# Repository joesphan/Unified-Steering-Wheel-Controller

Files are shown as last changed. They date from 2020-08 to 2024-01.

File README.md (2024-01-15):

# Unified Sim Controller

# Due to safety concerns with the mige 30 servo, this project was abandoned. The story goes is a bug occured, the wheel flung off, and drove into my monitor. In the future I might revisit with a appropriate sized servo motor.

##### Done:

- hardware done
- hardware differential centering upon power loss implemented
- firmware mostly complete
- overspeed safety implemented
- endstop damping implemented
- flowchart
- Wireless perhipherals: wheel buttons, pedals, shifter

##### Todo:

- documentation of code
- wheel damping adjustment
- figure out how to drop the 220v transformer
- add calibrate wheel button, gain adjustment potentiomter, etc.
- PCB boards
- standardized enclosure

## Theory of Operation

Controller for FFB wheel and peripherals

-Atmega 32u4

-[FFB Library](https://github.com/joesphan/ArduinoJoystickWithFFBLibrary) (thanks to the original author)

-Generic Servo Drive

-cutomizable and expandable controller

-wireless perhipheral add-ons (check docs for more detail)

## Servo Drive

The unified controller board's output is a standard CNC differential +/-10V + EN signal to control the motor.

## Encoder

Run with interrupts from servo drive. Two phase bog standard signal.

## Code Documentation

under \Documentation

## DIY kits and fully assembled

Want to help me pay for my tuition? DIY kits and fully assembled controller kits will be available soon. It will include a case and everything you need to assemble/PnP yourself. Target cost is around $50.

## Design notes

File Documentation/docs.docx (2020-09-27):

https://github.com/joesphan/FFB-Steering-Wheel

Design Goal:

Inspired by the Marlin firmware for 3d printers, the goal of this project is to create something that everyone can use, using a familiar Arduino interface, and create compatibility across a range of parts

Main features:

- Open source
  - Unlike MMOS, the source code can be viewed by everyone
  - Changes and improvements can be made/suggested by opening an issue on github
- Universal CNC servo drive control interface
  - The sim wheel controller is capable of driving servo drives with a +/- 10V signal
- Wireless peripherals
  - Pedals, yoke, shifters can all easily be added using one of the four auxiliary DB9 ports, or through the wireless ESP8266 UDP interface
  - The ESP8266 UDP interface has a latency of 20ms
- Easy configuration
  - All the parameters are set via the #defines tab

Basic Connection:

The minimal connections require a set of feedback and control signals to the servo drive.

The connections and code naming conventions are as follows:

Name | Pin | Description
DI1 | 10 | -10V to EN motor, in reference to COM+
COM+ | 18 | See above
A+ | 1 | Encoder phase A, ref to DGND
B+ | 3 | Encoder phase B, ref to DGND
DGND | 9 | Digital ground
AS+ | 20 | Differential + of control, +/-10V
AS- | 19 | Differential - of control, +/-10V
AGND | 22 | Differential ground reference

Firmware Setup:

Everything is contained under the defines tab

1. //Safetys
2. #define MAX_RPM 1
3. #define MOT_EN_PIN 7
5. //encoder parameters
6. #define MAX_STEPS 15000 //maximum number of steps one way
7. #define MAX_FULL_STEPS (MAX_STEPS * 2) //max number of steps total
9. //encoder HW
10. #define ENCODER1_PIN 3 //must support external interrupt
11. #define ENCODER2_PIN 2 // "" "" "" ""
13. //encoder RPM detect
14. #define ENCODER_1_REV 10000
15. #define RPM_DIVIDEND (60000000 / ENCODER_1_REV)
17. //motor control HW
18. #define ADC_PIN 5
20. //endstop damping settings: https://www.desmos.com/calculator/rhyetd6p3d
21. #define ENDSTOP_FACTOR 2.5 //dampening factor when turned past full lock
22. #define MAX_OVERTRAVEL 100 //how much overtravel steps is allowed before full force is applied
23. #define BIT_DEPTH 2048
25. //endstop rebound settings:
26. #define REBOUND_FORCE 50 //rebound force proportion to speed
28. //endstop spring length
29. #define OVERTRAVEL_SLOPE (BIT_DEPTH / MAX_OVERTRAVEL) //internal calcs

formatter (http://www.planetb.ca/syntax-highlight-word)

Some of the settings that require more thought are the rebound and dampening settings.

For endstop dampening, one can refer to this desmos graph (https://www.desmos.com/calculator/v05nhapfn8) when the wheel is moving towards more overtravel.

Endstop rebound dampening of is just a linear relationship between speed towards wheel center and REBOUND_FORCE

A library is used for communication with the PC. Be sure to use my fork (https://github.com/joesphan/ArduinoJoystickWithFFBLibrary), as it offers 12 bit (adjustable) FFB resolution, rather than fixed 8 bit.

Flow Diagrams:

- PID Loop:

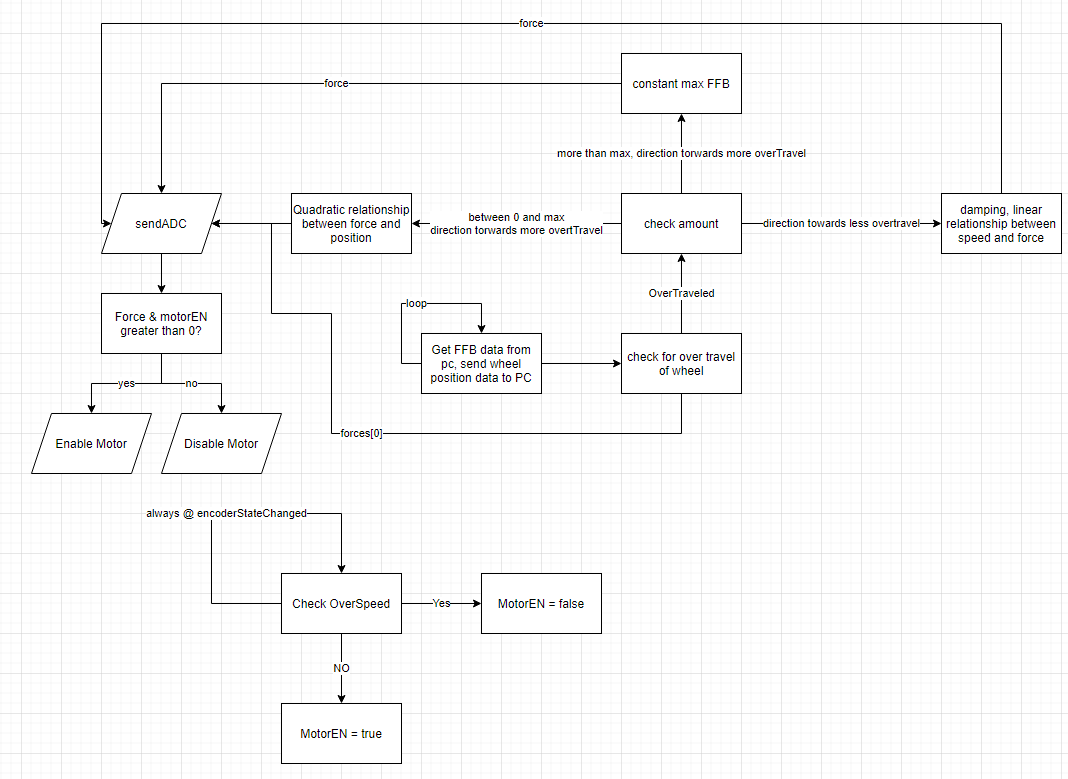
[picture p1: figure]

- Hardware Diagram:

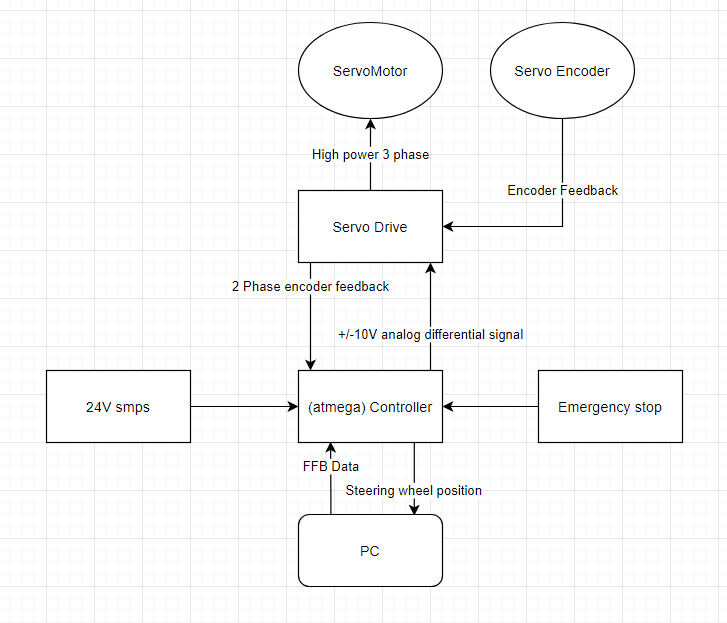
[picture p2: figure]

- Controller circuit flow diagram:

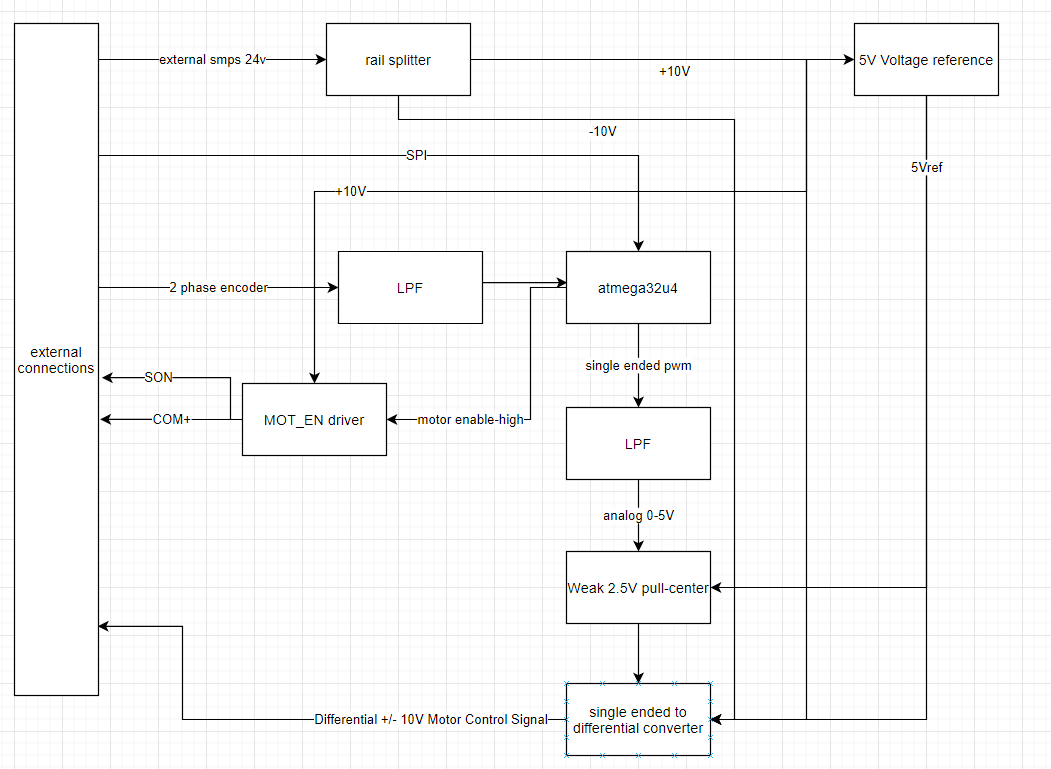
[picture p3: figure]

Wired Peripherals:

- All the remaining pins on the Arduino micro have been broken out to the DB9
- The pinouts can be found under fullschematic.dch/.pdf

Wireless Peripherals:

This method requires building a ESP8266 DB9 wireless adapter and plugging into DSUB-1. The ESP Wi-Fi receiver will communicate to the ATMega32u4 via UART. A custom packet is used to communicate information between peripheral and controller, through Wi-Fi UDP. The UDP packet is as follows:

Function | HEADER | Byte 1 | | | | | | | | Byte 2 | | | | | | | | Byte 3 | Byte 4 | Byte 5 | Byte 6 | Byte n
| | Bit7 | Bit6 | Bit5 | Bit4 | Bit3 | Bit2 | Bit1 | Bit0 | Bit7 | Bit6 | Bit5 | Bit4 | Bit3 | Bit2 | Bit1 | Bit0
Button input 1 | ‘A’ | | | | | | Horn (Button18) | Left shift paddle (Button0) | Right shift paddle (Button 1)
Axis input 1 | ‘B’ | Throttle, high 8 bits of the 16 | | | | | | | | Throttle, low 8 bits of the 16 | | | | | | | | Brake, high 8 bits of the 16 | Brake, low 8 bits of the 16 | Clutch, high 8 bits of the 16 | Clutch, low 8 bits of the 16
Button input 2 | ‘C’ | Reverse gear (Button2) | Gear 1 (Button3) | Gear 2 (Button4) | Gear 3 (Button5) | Gear 4 (Button6) | Gear 5 (Button7) | Gear 6 (Button8) | Gear 7 (Button9) | Gear 8 (Button10) | Gear 9 (Button11) | Gear 10 (Button12) | Shifter console button 1 (Button13) | Shifter console button 2 (Button14) | Shifter console button 3 (Button15) | Shifter console button 4 (Button16) | Shifter console button 5 (Button17)
Axis input 2 | ‘D’ | Handbrake, high 8 bits of the 16 | | | | | | | | Handbrake, low 8 bits of the 16

Coding conventions:

0x01 is recognized as HIGH for buttons, therefore it is active HIGH.

0x00 is recognized as LOW for buttons

The peripheral will automatically connect to the host Wi-Fi access point and send the packet to the host ESP8266 via UDP.

AP: SimInput

Key: 12345678

IP to send to: 192.168.4.1

Port to send to: 4210

Official Peripheral Documentation

Please open an issue and provide documentation, and Github page link to get the peripheral officially listed.

Shifter Paddles

Github: https://github.com/joesphan/Wireless-shifter-Paddles

Header used: ‘A’

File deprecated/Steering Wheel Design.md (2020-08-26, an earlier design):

# Custom Steering Wheel

## Theory of Operation

-needs to be easy to replicate on the HFT corded drill

-Atmega 32u4

-[FFB Library](https://github.com/YukMingLaw/ArduinoJoystickWithFFBLibrary) (thanks!)

-drill motor for "direct drive"

-minimize the use of 3d printed high stress components

-3d print a encoder wheel and use IR sensors to implement a rotary encoder built into the motor

-old 2 bay NAS chassis for housing

## Schematics

[Complete Schematic (pdf)](https://github.com/joesphan/Fullmotion-Racing-Sim/blob/master/Steering%20Wheel/Controller/Schematics%20and%20simulation/FullSchematic.pdf)

[Complete Schematic (diptrace)](https://github.com/joesphan/Fullmotion-Racing-Sim/blob/master/Steering%20Wheel/Controller/Schematics%20and%20simulation/FullSchematic.dch)

Note: 12V net port is not actually 12V

## MadCatz xbox wheel

| Color/Stripe | Function |
| :---: | :---: |
| Blue/Black | GND |
| Green/White | Y |
| Green | X |
| Orange/White | B |
| Yellow/Black | A |
| Blue/White | RSB |
| Red/White | LSB |
| Blue | RB (Flappy paddle right) |
| [Brown](https://youtu.be/lzqCQxi3ENE) | LB (Flappy paddle left)  |
| Yellow/Orange | Back |
| Black | Start |
| Gray | Xbox Button |
| Yellow | Up |
| Gray/White | Down |
| Brown/White | Left |
| Orange | Rumble Motor Left |
| Purple | Rumble Motor Right |
| Red | Vcc |
| White | 5V |
| Orange/Black | P1 LED (active low, use resistor) |
| Red/Black | P2 LED (active low, use resistor) |
| Brown/Black | P3 LED (active low, use resistor) |
| Pink/Black | P4 LED (active low, use resistor) |

The steering wheel will carry an onboard SPI IO expander (mcp23s17), interfacing with all the buttons.

A spring cable will carry the SPI signals between the 32u4 and the wheel.

## Microcontroller Flowchart

diagram

Inside the ATmega32u4, the code will go something like this:

diagram

## Rotary Encoder

To eliminate the need of any mechanical connection between the drill and parts, the cooling fan inside the motor will be replaced with a rotary encoder wheel.

## H bridge Driver

This is a basic H bridge driver, supports PWM. Only thing is that there is absolutely no circuit protection, so should both analog pwm inputs be active, the HEXFETS will be no more.

The extra transistors tacked on are to create a 12V gate drive.

I simulated the circuit in [circuitmod](https://sourceforge.net/projects/circuitmod/). Although I had access to MultiSim through my uni, the mentioned software is more accessible to most people and is fine.

HBridgeSimulation

The non-full voltage swing across the 10 ohm is caused by the limitation of the simulator's mosfet model. Putting another one in parallel solves this issue, by using a more appropriate MOSFET in the final design will be a better solution

## Power supply

The drill is a 120V drill. Running it on 12V DC provides good Locking torque, yet lacks power to come out of a locked stall.

A voltage doubler circuit would be utilized to boost the voltage to a decent amount.

### Transformer calculations

TrafoInductanceTest

The circuit consisted of the transformer (secondary open) and a 100 ohm resistor in series. The smaller waveform is the measurement across the resistor while a signal was applied.

Calculations

formula

formula

formula

formula

formula

### Voltage doubler and filter simulation

PowerSupplySim

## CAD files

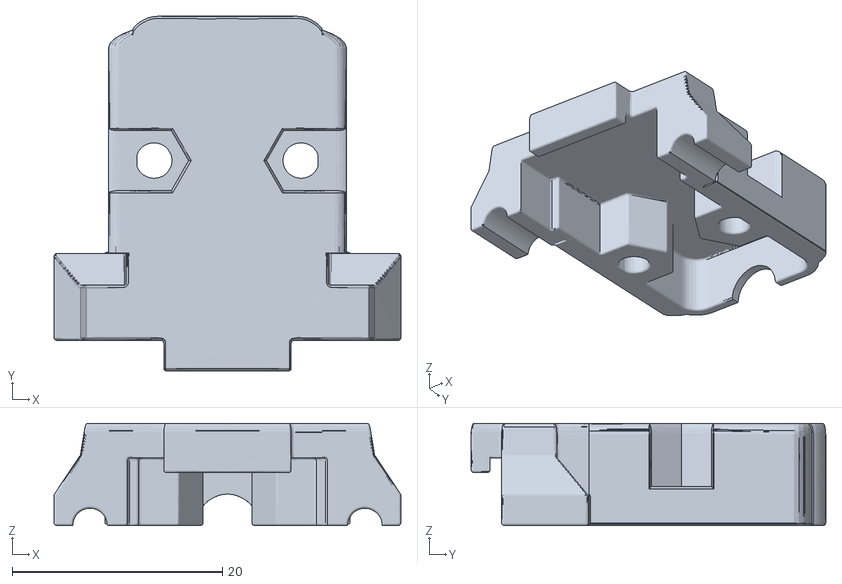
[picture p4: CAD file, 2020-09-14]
Chassis/DSub/DB9-industrial.stl
33.0 x 33.7 x 9.73

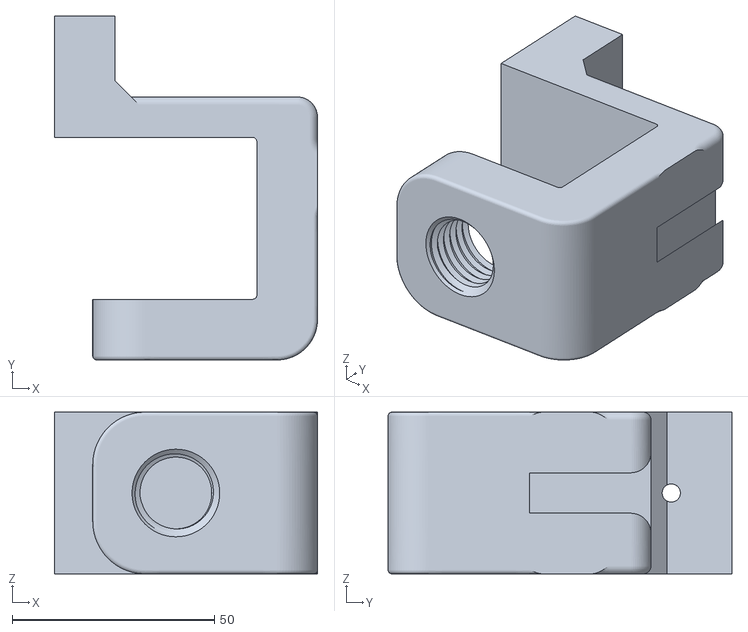
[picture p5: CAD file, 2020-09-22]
Wheel/clamp mount/clamp.stl
65.0 x 85.0 x 40.0

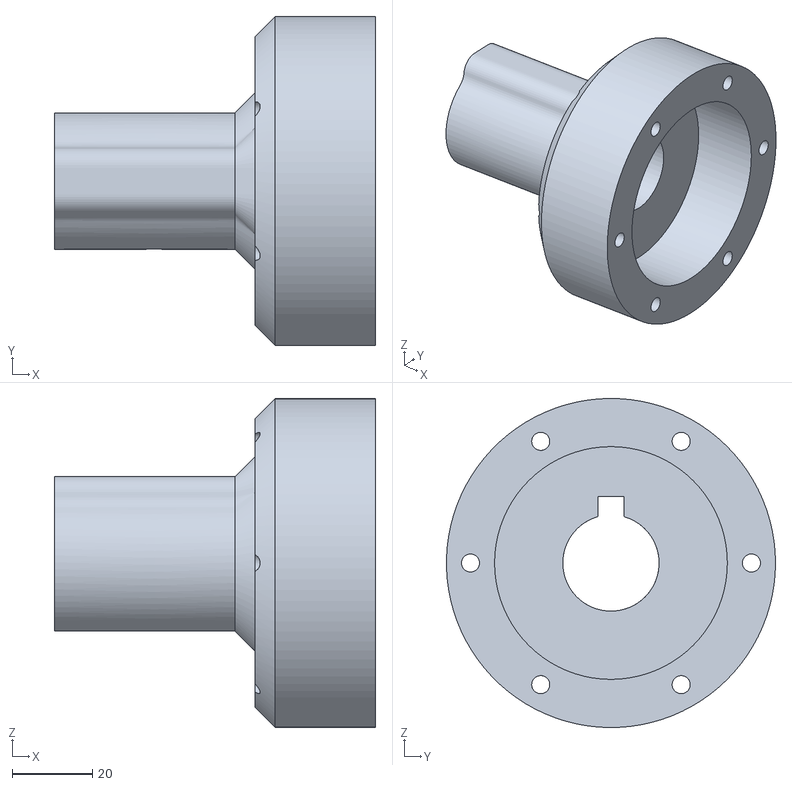
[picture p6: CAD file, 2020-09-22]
Wheel/6 bolt steering wheel adapter/adapter.stl
80.0 x 82.0 x 82.0

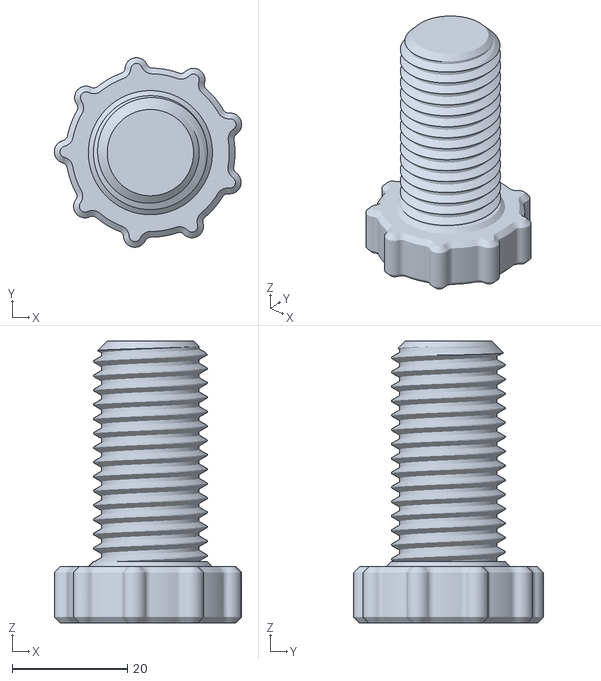
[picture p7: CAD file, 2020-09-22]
Wheel/clamp mount/screw.stl
32.6 x 33.0 x 49.0

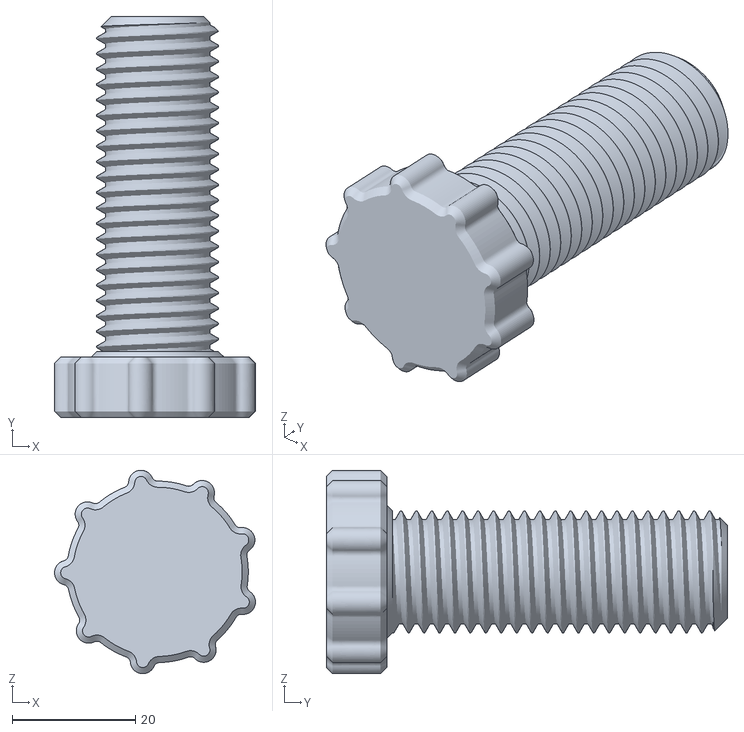
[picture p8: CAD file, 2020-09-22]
Wheel/clamp mount/screw_long.stl
32.6 x 65.0 x 33.0

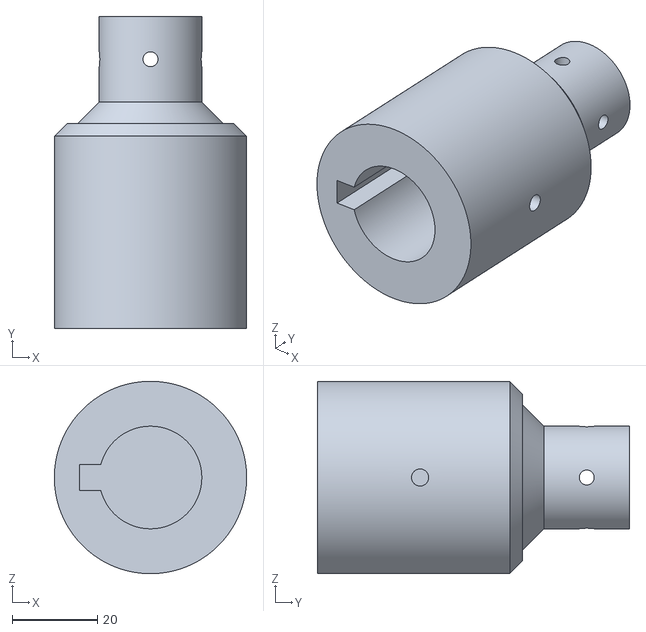
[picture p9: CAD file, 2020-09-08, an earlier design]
deprecated/3d models/Xbox Madcatz Wheel/shaft adapter.stl
45.0 x 73.0 x 45.0

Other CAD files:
Chassis/ESP Receiver/OldVersions/dongle shell.0001.ipt
Chassis/ESP Receiver/dongle shell.ipt
Wheel/6 bolt steering wheel adapter/OldVersions/adapter.0003.ipt
Wheel/6 bolt steering wheel adapter/adapter.ipt
deprecated/3d models/Assembly1.iam
deprecated/3d models/IRSensorMount.ipt
deprecated/3d models/IRSensorMountOtherSide.ipt
deprecated/3d models/OldVersions/Assembly1.0007.iam
deprecated/3d models/OldVersions/Bearing.0002.ipt
deprecated/3d models/OldVersions/IRSensorMount.0002.ipt
deprecated/3d models/OldVersions/IRSensorMount.0007.ipt
deprecated/3d models/OldVersions/IRSensorMountOtherSide.0007.ipt
deprecated/3d models/OldVersions/back plate.0010.ipt
deprecated/3d models/OldVersions/back plate.0015.ipt
deprecated/3d models/OldVersions/front plate.0009.ipt
deprecated/3d models/OldVersions/motor mount.0002.ipt
deprecated/3d models/OldVersions/rotary encoder.0003.ipt
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

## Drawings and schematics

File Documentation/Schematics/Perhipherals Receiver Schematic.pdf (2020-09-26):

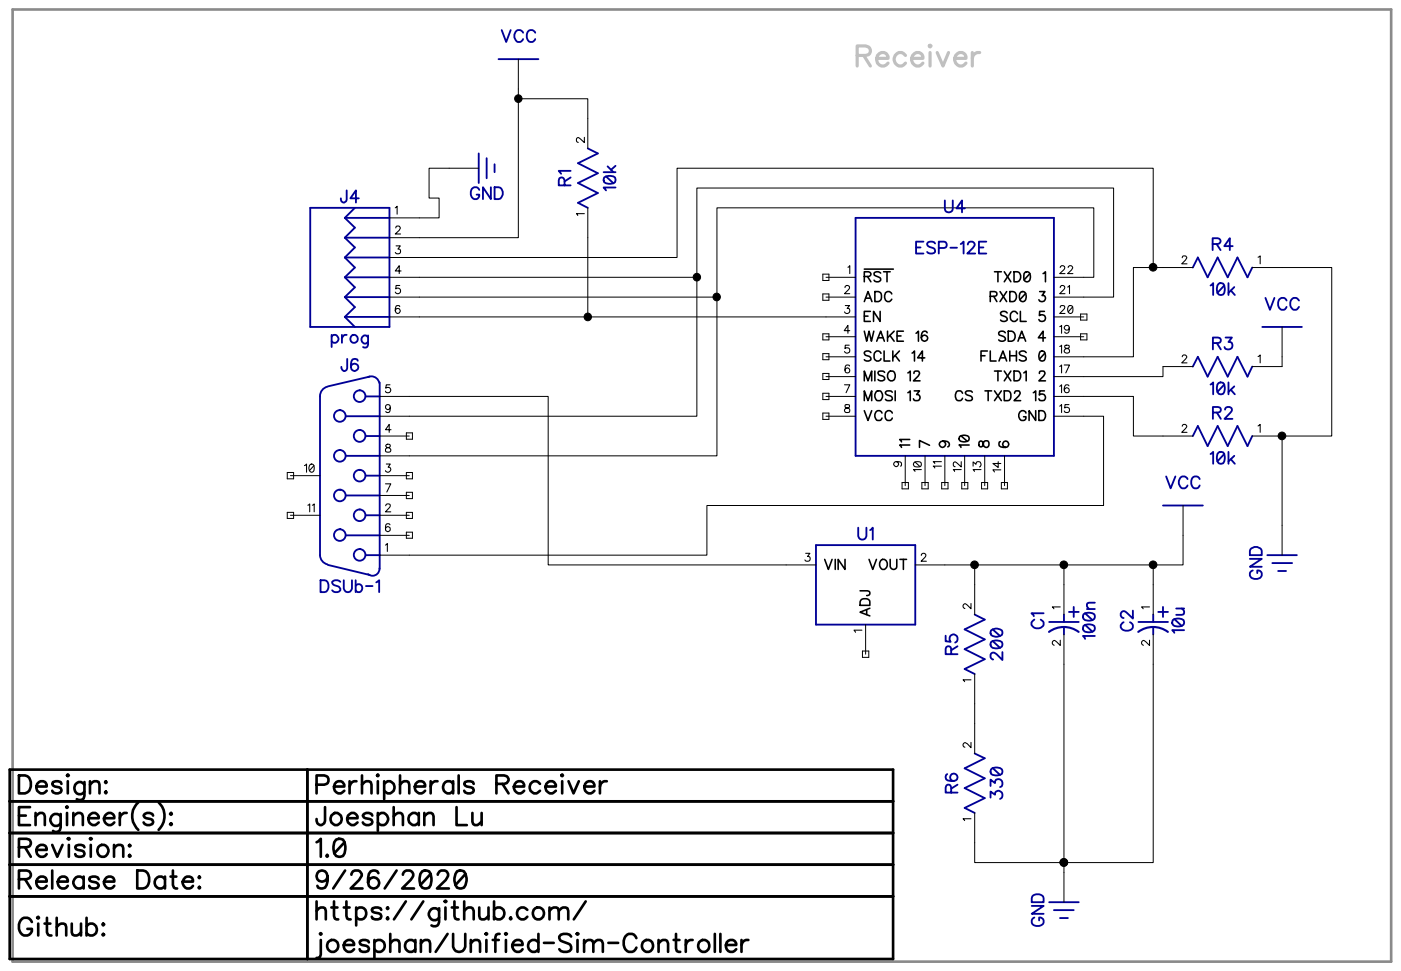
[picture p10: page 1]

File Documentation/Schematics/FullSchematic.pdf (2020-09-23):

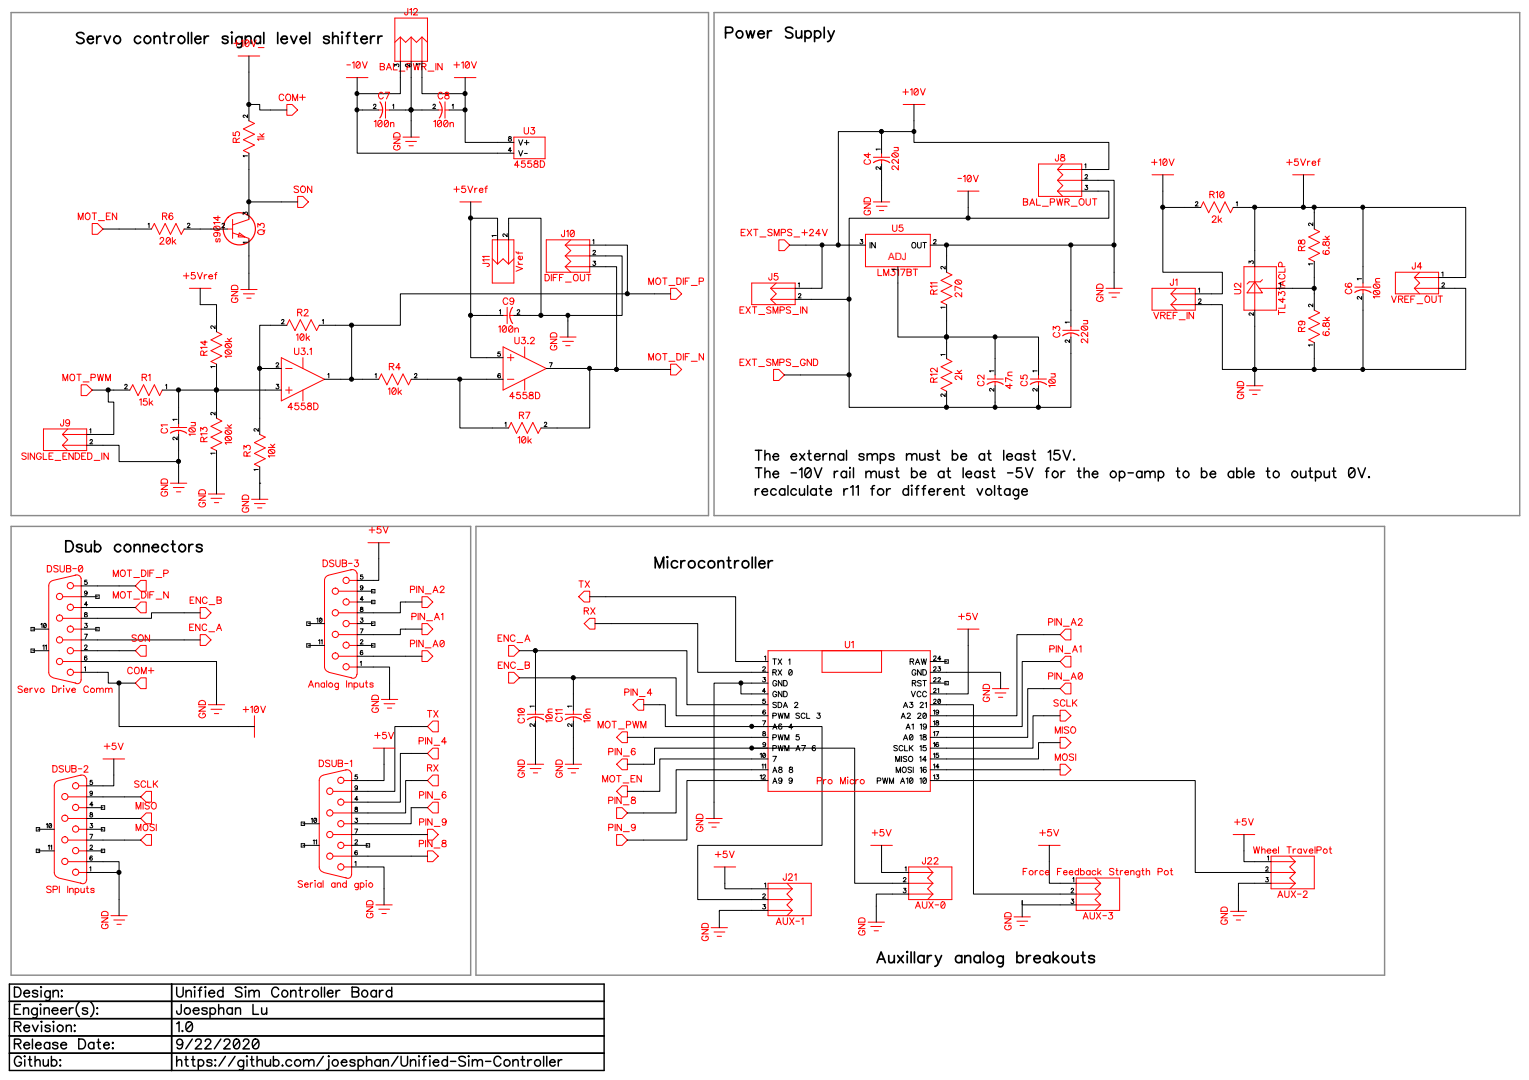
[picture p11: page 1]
ADJ

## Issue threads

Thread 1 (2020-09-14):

I have a project about racing simulation direct drive steering wheel diy

HUANGJIN169, 2020-09-14:
Hello there
How do you use these firmware
I have a project about racing simulation direct drive steering wheel diy
https://hackaday.io/project/168801-diy-mmos-ffb-stm32-and-servo-drive-servo-motor
I need a perfect firmware to control
can you do it?
Thank you!

joesphan, 2020-09-14:
Hello! I saw your project and was part of my inspiration. I will do a push later today for the schematic and firmware. It's pretty self explanatory.
The goal of this project is fully open source, unlike MMOS. The MCU is atmega32u4, I'm sure it can be implemented with the STM32 through stm32duino, no library dependencies are being used. The controls are a PWM output, with 0 being max force servo left, 4096 being max force servo right.
Hopefully I can get it all documented before uni starts again.

HUANGJIN169, 2020-09-15:
Thank you for your reply
If you have time to complete my project control firmware
You send me the first time
I test if it can be used
Thank you
You have worked hard

Joesphan Lu <notifications@github.com> 于2020年9月15日周二 上午12:20写道：

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

HUANGJIN169, 2020-09-15:
I come from Google Translate, it may not be very standard
Hope to understand

DIY Racing Simul <huangjin169@gmail.com> 于2020年9月15日周二 下午5:09写道：

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

joesphan, 2020-09-15:
Could you put what you wanted to say in Chinese underneath? I can read Chinese.

HUANGJIN169, 2020-09-16:
我意思是，如果你把固件设计完成了
就把固件和运行软件发给我，我来测试固件是不是可以控制伺服驱动和电机
我这个直驱模拟方向盘是由伺服驱动和伺服电机进行diy的
所以我需要一个属于自己的固件和控制界面
我也希望你能做出来的固件 这样我们以后就有自己的固件了
谢谢你的回复！

Joesphan Lu <notifications@github.com> 于2020年9月15日周二 下午9:56写道：

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

HUANGJIN169, 2020-09-16:
https://github.com/hoantv
还有，这里有一个也开放项目，他这个代码是可以完全和MMOS一样的
他这个固件也可以完全控制我的diy项目的
不过，他设计的界面不是很完美

DIY Racing Simul <huangjin169@gmail.com> 于2020年9月16日周三 下午12:44写道：

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

joesphan, 2020-09-16:
Sounds good, I will put a release once I finish testing the wheel. Pcb are in shipping right now. Can you tell me the drawbacks of hoanTV's firmware?

HUANGJIN169, 2020-09-17:
它的缺点，界面不是很完美
固件好在优化中
使用hoanTV固件的时候和MMOS一样的
就是界面不一样而且
我想要的界面就是像Simucube一样

Joesphan Lu <notifications@github.com> 于2020年9月16日周三 下午9:47写道：

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

HUANGJIN169, 2020-09-17:
https://github.com/SimuCUBE/SimuCUBE-OpenSource-Firmware
你可以使用这个开源固件做出来一个完美自己的固件吗？
我非常喜欢这个固件
不幸的是，我的伺服驱动器和我的伺服电机不能使用它
辛苦你了😧

DIY Racing Simul <huangjin169@gmail.com> 于2020年9月17日周四 下午12:47写道：

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

joesphan, 2020-09-17:
I'm not planning on putting in a computer interface, as adjusting the
settings in defines.ino is a one time thing. However, to make setup easier,
a c# program that sets the defines.ino parameters, compiles and flashes,
could be done. Generally speaking though, i have made it super easy to
change settings in firmware.

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

HUANGJIN169, 2020-09-18:
好的
能使用就可以
不管怎么样
这也是属于完美自己的固件了

Joesphan Lu <notifications@github.com> 于2020年9月17日周四 下午1:34写道：

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

HUANGJIN169, 2020-09-18:
RaceManager(V3.3) - 速魔.zip
<https://drive.google.com/file/d/1NUXp7nSRQALGHQiRQVS_OVzfGvQ5KJBX/view?usp=drive_web>
你可以解压这个固件
它来自中国一个模拟器的固件
它仿制Simucube固件的界面
这他们应该使用的是Simucbe开放软件进行制作的

DIY Racing Simul <huangjin169@gmail.com> 于2020年9月18日周五 下午12:24写道：

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

TadyTheFish, 2020-12-02:
Can't  compile for a STM32 :(

joesphan, 2020-12-02:
> Can't  compile for a STM32 :(

The USB libraries for stm32 are different. I couldn't find stm32 libraries that also did force feedback.

HUANGJIN169, 2020-12-11:
你好大哥
最近在忙工作吗？
我们之前谈话题，说要做模拟赛车方向盘控制软件的，你还记得吗？大哥
如果你有时间能帮助我写一个软件吗？
谢谢！

DIY Racing Simul <huangjin169@gmail.com> 于2020年9月18日周五 下午6:26写道：

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
>>> I'm not planning on putting in a computer interface, as adjusting the
>>> settings in defines.ino is a one time thing. However, to make setup
>>> easier,
>>> a c# program that sets the defines.ino parameters, compiles and flashes,
>>> could be done. Generally speaking though, i have made it super easy to
>>> change settings in firmware.
>>>
>>> On Thu, Sep 17, 2020, 3:47 AM huangjin <notifications@github.com> wrote:
>>>
>>> > 它的缺点，界面不是很完美
>>> > 固件好在优化中
>>> > 使用hoanTV固件的时候和MMOS一样的
>>> > 就是界面不一样而且
>>> > 我想要的界面就是像Simucube一样
>>> >
>>> > Joesphan Lu <notifications@github.com> 于2020年9月16日周三 下午9:47写道：
>>> >
>>> > > Sounds good, I will put a release once I finish testing the wheel.
>>> Pcb
>>> > are
>>> > > in shipping right now. Can you tell me the drawbacks of hoanTV's
>>> > firmware?
>>> > >
>>> > > —
>>> > > You are receiving this because you authored the thread.
>>> > > Reply to this email directly, view it on GitHub
>>> > > <
>>> >
>>> https://github.com/joesphan/FFB-Steering-Wheel/issues/1#issuecomment-693627641
>>> >,
>>> >
>>> > > or unsubscribe
>>> > > <
>>> >
>>> https://github.com/notifications/unsubscribe-auth/ALJJK7T65L7PKT3ADJYIH4TSGEI47ANCNFSM4RLSAXBA
>>> >
>>> >
>>> > > .
>>> > >
>>> >
>>> > —
>>> > You are receiving this because you commented.
>>> > Reply to this email directly, view it on GitHub
>>> > <
>>> https://github.com/joesphan/FFB-Steering-Wheel/issues/1#issuecomment-694151862
>>> >,
>>> > or unsubscribe
>>> > <
>>> https://github.com/notifications/unsubscribe-auth/AJE33QUSPOHWXFD7YZGOD23SGHSLVANCNFSM4RLSAXBA
>>> >
>>> > .
>>> >
>>>
>>> —
>>> You are receiving this because you authored the thread.
>>> Reply to this email directly, view it on GitHub
>>> <https://github.com/joesphan/FFB-Steering-Wheel/issues/1#issuecomment-694172200>,
>>> or unsubscribe
>>> <https://github.com/notifications/unsubscribe-auth/ALJJK7QBXMJJUT47HOTEFVDSGHX3TANCNFSM4RLSAXBA>
>>> .
>>>
>>

joesphan, 2020-12-11:
@HUANGJIN169
Nope, still very busy. Just got done with finals, have a bathroom to finish installing.
I'm thinking of transitioning to a closed loop stepper system instead. The HB860 closed loop type stepper motor controller:
https://a.aliexpress.com/_mNXgmJx
Looks like it has much more promising results when simulating torque on a wheel:
https://youtu.be/SoRdEAm1auk
The "return to center" is implemented much better than any arduino can do.
Another big concern is the safety with servos. My wheel flew off at a high speed when the arduino lost power, as it depended on a single ended to differential signal converter.
Let me know your thoughts, next update should come within the next six months.

HUANGJIN169, 2020-12-12:
We can study this project together
I feel that this project can imitate a simulated racing car to control the
joint force feedback system
https://github.com/rene-dev/stmbl

Joesphan Lu <notifications@github.com> 于2020年12月12日周六 上午4:03写道：

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

joesphan, 2020-12-12:
> We can study this project together I feel that this project can imitate a simulated racing car to control the joint force feedback system https://github.com/rene-dev/stmbl Joesphan Lu <notifications@github.com> 于2020年12月12日周六 上午4:03写道：
> […](#)
> @HUANGJIN169 <https://github.com/HUANGJIN169> Nope, still very busy. Just got done with finals, have a bathroom to finish installing. I'm thinking of transitioning to a closed loop stepper system instead. The HB860 closed loop type stepper motor controller: https://a.aliexpress.com/_mNXgmJx Looks like it has much more promising results when simulating torque on a wheel: https://youtu.be/SoRdEAm1auk The "return to center" is implemented much better than any arduino can do. Another big concern is the safety with servos. My wheel flew off at a high speed when the arduino lost power, as it depended on a single ended to differential signal converter. Let me know your thoughts, next update should come within the next six months. — You are receiving this because you were mentioned. Reply to this email directly, view it on GitHub <[#1 (comment)](https://github.com/joesphan/Unified-Steering-Wheel-Controller/issues/1#issuecomment-743399089)>, or unsubscribe <https://github.com/notifications/unsubscribe-auth/ALJJK7SIDF6SMALPTGDGMJTSUJ3HNANCNFSM4RLSAXBA> .

I am more interested in using an existing solution. The LeadShine drives allow serial control via USB:
https://www.youtube.com/watch?v=xJ97x_2b4yk

Peter11k, 2021-09-03:
Hello, I am very interested in your DIY. Has it been finished now?

HUANGJIN169, 2022-01-25:
> @HUANGJIN169 不，还是很忙。刚做完决赛，有一个浴室来完成安装。 我正在考虑改用闭环步进系统。HB860 闭环式步进电机控制器： [https](https://a.aliexpress.com/_mNXgmJx) ://a.aliexpress.com/_mNXgmJx 在模拟车轮上的扭矩时看起来更有希望的结果： [https](https://youtu.be/SoRdEAm1auk) ://youtu.be/SoRdEAm1auk “回归中心”实施得比任何 arduino 都好得多。 另一个大问题是伺服系统的安全性。当 arduino 断电时，我的轮子高速飞了起来，因为它依赖于单端到差分信号转换器。 让我知道您的想法，下一次更新应该在接下来的六个月内发布。

> @HUANGJIN169 Nope, still very busy. Just got done with finals, have a bathroom to finish installing. I'm thinking of transitioning to a closed loop stepper system instead. The HB860 closed loop type stepper motor controller: https://a.aliexpress.com/_mNXgmJx Looks like it has much more promising results when simulating torque on a wheel: https://youtu.be/SoRdEAm1auk The "return to center" is implemented much better than any arduino can do. Another big concern is the safety with servos. My wheel flew off at a high speed when the arduino lost power, as it depended on a single ended to differential signal converter. Let me know your thoughts, next update should come within the next s

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

你好大哥，我不知道什么时候退订了Github信息，你还有其他联系方式吗？比如Facebook账号或者WhatsApp还有Discord你有这些账号联系方式吗？如果有这些账号我们沟通更方便

joesphan, 2022-01-25:
@Peter11k > Hello, I am very interested in your DIY. Has it been finished now?

Far from it. I will revisit this probably in the very future. Personally, I'm a few months away from graduation and am busy looking for jobs and working on my senior project.

joesphan, 2022-01-25:
@HUANGJIN169 you can reach me via my email joesphanlu@gmail.com

HUANGJIN169, 2022-01-25:
OK, thank you for your reply.

Closed 2022-01-26.

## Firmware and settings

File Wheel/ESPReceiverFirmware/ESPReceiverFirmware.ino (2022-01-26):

#include <ESP8266WiFi.h>
#include <WiFiUdp.h>
#include <SPI.h>

#define APSSID "SimInput"
#define APPSK  "12345678"
#define PACKET_SIZE 9

#define DEBUG
const char *ssid = APSSID;
const char *password = APPSK;
unsigned int localUdpPort = 4210;
byte incomingPacket[9];

WiFiUDP Udp;

void setup() {
#ifdef DEBUG
  Serial.begin(9600);
#endif
  delay(1000);
  WiFi.softAP(ssid, password);
  IPAddress myIP = WiFi.softAPIP();
  Udp.begin(localUdpPort);
  SPI.begin();
}

void loop() {
  int packetSize = Udp.parsePacket();
  if (packetSize) //non blocking
  {
    int len = Udp.read(incomingPacket, PACKET_SIZE);
    if (len > 0)
    {
      incomingPacket[len] = 0;
    }
    for (int i = 0; i < 9; i++) {
#ifdef DEBUG
      Serial.print(incomingPacket[i]);
#endif
      SPI.transfer(incomingPacket[i]);
      incomingPacket[i] = 0;
    }
#ifdef DEBUG
      Serial.println("   ");
#endif
  }
}

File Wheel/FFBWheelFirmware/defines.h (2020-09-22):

//Safetys
#define MAX_RPM 1
#define MOT_EN_PIN 7

//encoder parameters
#define MAX_STEPS 15000                         //maximum number of steps one way
#define MAX_FULL_STEPS (MAX_STEPS * 2)        //max number of steps total

//encoder HW
#define ENCODER1_PIN 3          //must support external interrupt
#define ENCODER2_PIN 2          // ""    ""       ""       ""

//encoder RPM detect
#define ENCODER_1_REV 10000
#define RPM_DIVIDEND (60000000 / ENCODER_1_REV)

//motor control HW
#define ADC_PIN 5               //must be 5 for 12 bits

//endstop damping settings: https://www.desmos.com/calculator/rhyetd6p3d
#define ENDSTOP_FACTOR 2.5                  //dampening factor when turned past full lock
#define MAX_OVERTRAVEL 100        //how much overtravel steps is allowed before full force is applied
#define BIT_DEPTH 2048

//endstop rebound settings:
#define REBOUND_FORCE 50            //rebound force proportion to speed

//endstop spring length
#define OVERTRAVEL_SLOPE (BIT_DEPTH / MAX_OVERTRAVEL)   //internal calcs

//SPI SS pin
//#define SS_PIN 10

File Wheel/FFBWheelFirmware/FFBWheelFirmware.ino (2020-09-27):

/*
   Attribution-NonCommercial-ShareAlike 4.0 International (CC BY-NC-SA 4.0) (c) 2020 Joesphan Lu
*/
#include "defines.h"
#include "Joystick.h"


extern int Position;
extern int32_t forces[2];
extern int motorForce;
extern int prevOverTravel;
extern int diff;
extern uint32_t stepTime;
extern int dir;


void setup() {
  Serial.begin(115200);

  ADCDriverInit();
  servoDriveInit();
  EncoderDriverInit();
  RFReceiverInit();
  JoystickInit();
}

void loop() {
  int overTravel = CheckMaxAngle();
  JoystickRun();
  if (!overTravel) { //if not at max angle
    servoDrive(-forces[0]);
    prevOverTravel = 0;
  } else {
    endStopDrive(overTravel);
  }
  //debug
  SendSerial(Position, forces[0], motorForce, overTravel, prevOverTravel, getSpeed());
}

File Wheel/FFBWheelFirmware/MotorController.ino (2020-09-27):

#include "defines.h"
/*
     MotorController: controls the servo drive
*/
int motorForce;
extern int motorEN;
int prevOverTravel;

/*
   init with diff signal of 0
*/
void servoDriveInit() {
  pinMode(MOT_EN_PIN, OUTPUT);
  motorForce = BIT_DEPTH;
  ADCSend(motorForce);
}

/*
   servoDrive: communicates with the servo drive, input as a force direction
   input is an 11 bit value left/right; -2048/2048
*/
void servoDrive(int force) {
  motorForce = (force + 2048);
  ADCSend(motorForce);
  if (force && motorEN) {
    digitalWrite(MOT_EN_PIN, HIGH);
  } else {
    //disable when not intending to write
    digitalWrite(MOT_EN_PIN, LOW);
  }
}
/*
    endStopDrive:
    Over travel (OT) as input, - as left + as right
    creates a dampened force
    adjustable quadratic dampening
    adjustable rebound damping
    return spring damping implemented
*/
void endStopDrive(int overTravel) {
  int absoluteOverTravel = abs(overTravel);
  int diff = absoluteOverTravel - prevOverTravel;
  //int dir = -(overTravel / absoluteOverTravel);
  int dir = -(overTravel / absoluteOverTravel);
  if (absoluteOverTravel < MAX_OVERTRAVEL && diff > 0) {   //between 0 and MAX_OVERTRAVEL steps of OT, direction OT increasing
    //quadratic
    servoDrive(dir * (BIT_DEPTH * (pow(((float)absoluteOverTravel / MAX_OVERTRAVEL), ENDSTOP_FACTOR))));
    
  } else if (absoluteOverTravel > MAX_OVERTRAVEL && diff > 0) { //more than MAX_OVERTRAVEL steps of OT, direction OT increasing
    
    servoDrive(dir * BIT_DEPTH);                                //direction * max force
    
  } else {                             //OT direction decreasing
    //rebound
    servoDrive(-dir * (REBOUND_FORCE * getSpeed()));    //rebound force dependent on (rebound) speed of wheel
  }
  prevOverTravel = absoluteOverTravel;
}

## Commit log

2020-08-26 initial move commit
    [Assembly1.0007.iam, Assembly1.iam, Bearing.0002.ipt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]
2020-09-08 Big Update
    [shaft adapter.0002.ipt, shaft adapter.ipt, shaft adapter.stl]
2020-09-14 issue #1
    [Assembly1.0007.iam, Assembly1.iam, Bearing.0002.ipt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]
2020-09-22 wireless perhipheral system implemented, docs and schematics updated
    [DB9-industrial.stl, adapter.0003.ipt, adapter.ipt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]
2020-09-26 wireless perhipheral receiver documented
2022-01-26 commited this
    yuh
    [dongle shell.0001.ipt, dongle shell.ipt, inside bracket.0001.ipt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]
